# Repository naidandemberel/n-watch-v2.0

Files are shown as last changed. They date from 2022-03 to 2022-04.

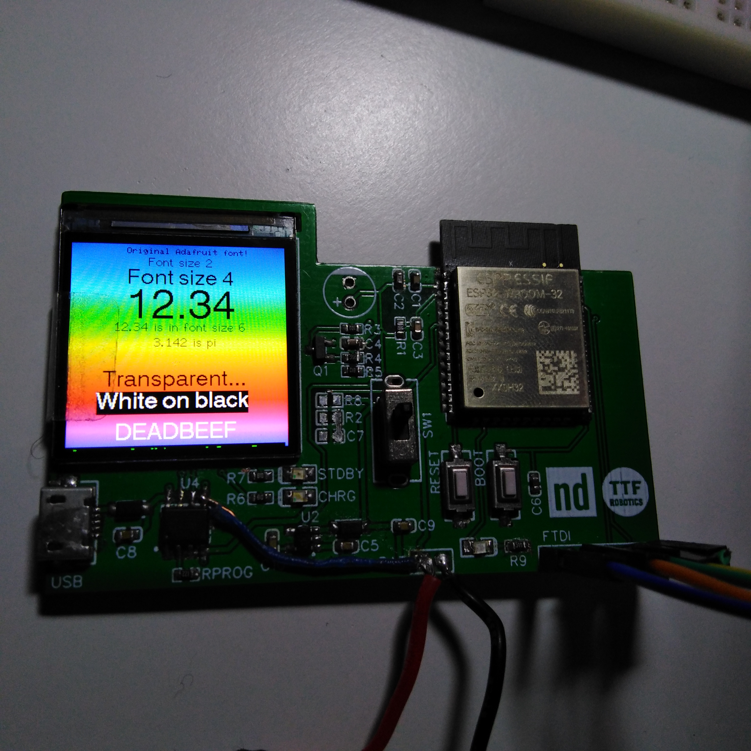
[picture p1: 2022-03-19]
Pictures/IMG_20211001_222228_1.jpg

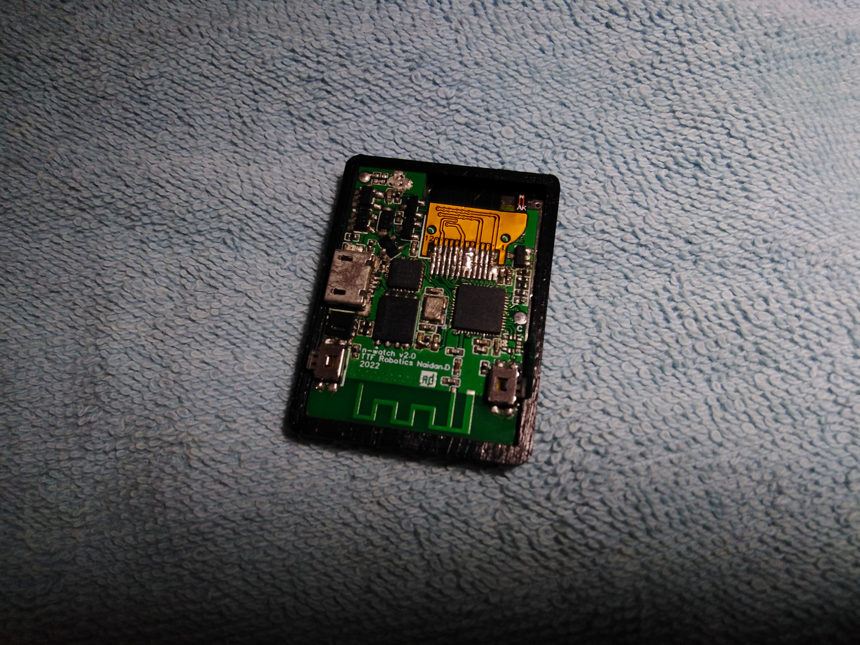
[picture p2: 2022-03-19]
Pictures/IMG_20220121_220617.jpg

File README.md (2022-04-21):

# n-watch-v2.0
n-watch v2.0 is an open source, hackable, smart watch based on ESP32. <br/>
Hackaday: https://hackaday.io/project/184473-n-watch-v20 for more information. <br/>



Hardware <br/>
• Microcontroller: ESP32-D0WDQ6-V3 <br/>
• Display: 240x240 ST7789 IPS <br/>
• Battery: 150mah LiPo <br/>
• Temperature sensor: SHT20 <br/>
• Battery charger IC: TP4054 <br/>
• Flash IC: W25Q32JVZPIQ <br/>
• USB to UART IC: CP2104 <br/>

Features <br/>
• Arduino based <br/>
• WiFi + Bluetooth 4.0 <br/>
• The case consists of 2 parts (bottom and top) <br/>
• 2 programmable buttons <br/>
• Shows time, date, voltage of battery, percent of battery, temperature <br/>
• Any 20mm watchband <br/>
• The battery life is horrible. I tried to minimize all the power consumption (3-4 hours) <br/>
• Has own app <br/>

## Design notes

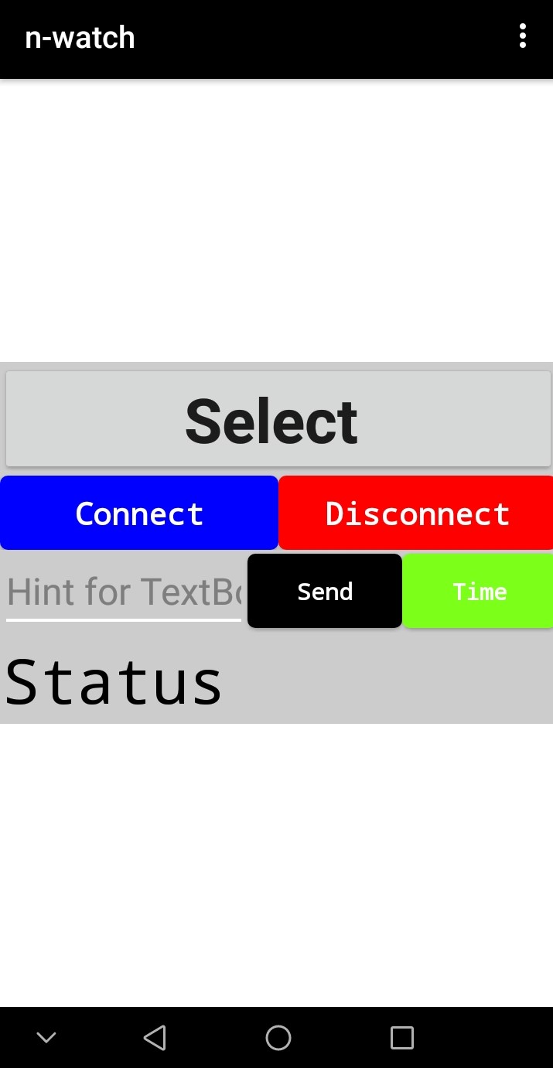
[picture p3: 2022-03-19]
n-watch v2.0 phone app/Pictures/Screenshot_20220319-151742.jpg

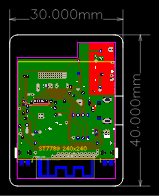
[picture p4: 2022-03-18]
Pictures/PCB_PCB_n-watch v2.0_2022-02-12.png

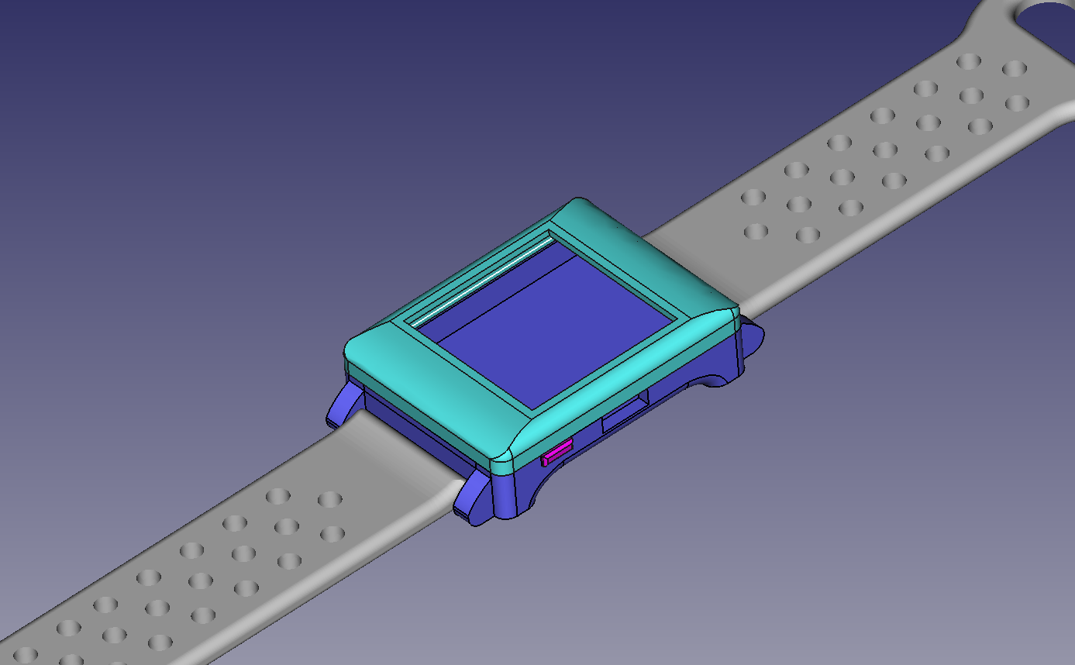
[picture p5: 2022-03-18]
Pictures/Screenshot 2022-02-20 202150.png

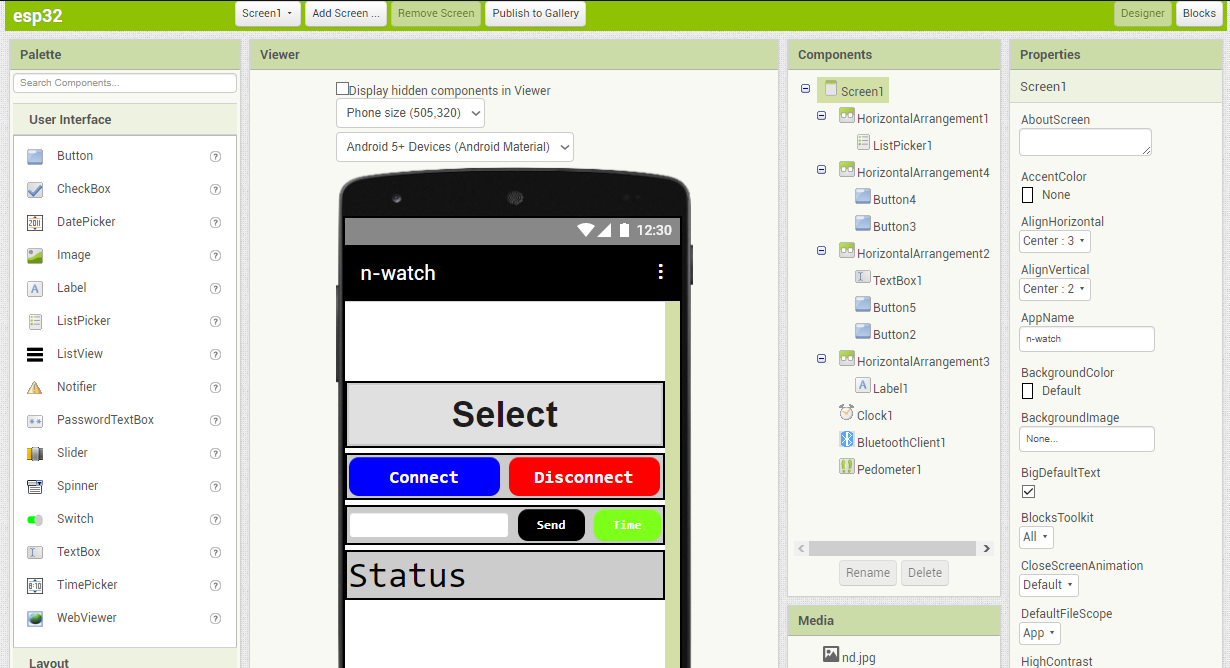
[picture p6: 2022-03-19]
n-watch v2.0 phone app/Pictures/Capture.PNG

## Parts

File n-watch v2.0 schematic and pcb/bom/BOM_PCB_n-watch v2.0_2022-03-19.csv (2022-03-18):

ID | Name | Designator | Footprint | Quantity | Manufacturer Part | Manufacturer | Supplier | Supplier Part | Price
1 | ST7789-240X240 COPY | U8 | ST7789-240X240_NAIDAN | 1
2 | K2-1114SA-A4SW-06 | SW1,SW2 | KEY-SMD_4P-L4.8-W4.6-P1.70-LS6.2 | 2 | K2-1114SA-A4SW-06 | HRO | LCSC | C136662 | 0.156
3 | CP2104-F03-GMR | U5 | QFN-24_L4.0-W4.0-P0.50-BL-EP2.6 | 1 | CP2104-F03-GMR | SILICON LABS | LCSC | C47015 | 2.361
4 | BMA400 | U10 | LGA-12_L2.0-W2.0-P0.50-BL | 1 | BMA400 | Bosch Sensortec | LCSC | C437655 | 5.28
5 | ESP32-D0WDQ6-V3 | U1 | QFN-48_L6.0-W6.0-P0.40-BL-EP4.2 | 1 | ESP32-D0WDQ6-V3 | ESPRESSIF 乐鑫 | LCSC | C967020 | 2.7
6 | MBR0530 | D2 | SOD-123_L2.8-W1.8-LS3.7-RD | 1 | MBR0530 | CJ | LCSC | C77336 | 0.033
7 | CJ2301 S1 | Q4 | SOT-23-3_L3.0-W1.7-P0.95-LS2.9-BR | 1 | CJ2301 S1 | CJ | LCSC | C8547 | 0.042
8 | 10k | R2,R4,R5,R6,R7,R10,R11,R12,R13,R15 | R0402 | 10
9 | 100k | R8,R9 | R0402 | 2
10 | RT9013-33GB | U2 | SOT-23-5 | 1 | RT9013-33GB | RICHTEK | LCSC | C47773 | 0.375
11 | 1uF | C3 | C0402 | 1
12 | 0.1uF | C1,C2,C9,C17 | C0402 | 4
13 | 12pF | C18,C19 | C0402 | 2
14 | 3.3nF/6.3V/(10%) | C20 | C0402 | 1
15 | 10nF/6.3V(10%) | C21 | C0402 | 1
16 | 4.7pF | C22 | C0402 | 1
17 | 2.4pF | C23 | C0402 | 1
18 | 2.4nH | L2 | L0402 | 1
19 | S8050 | Q1,Q2,Q3 | SOT-23-3_L2.9-W1.3-P1.90-LS2.4-BR | 3 | S8050 | JSMSEMI | LCSC | C916390 | 0.008
20 | 10 | R1 | R0402 | 1
21 | 1k | R3,R16 | R0402 | 2
22 | 20k(5%) | R14 | R0402 | 1
23 | 4.7k | R17,R18 | R0402 | 2
24 | W25Q32JVZPIQ | U3 | WSON-8_L6.0-W5.0-P1.27-BL-EP | 1 | W25Q32JVZPIQ | Winbond Elec | LCSC | C571260 | 0.844
25 | TP4054 | U4 | SOT-23-5_L3.0-W1.7-P0.95-LS2.8-BR | 1 | TP4054 | TOPPOWER | LCSC | C32574 | 0.161
26 | SHT20 | U9 | DFN-6_L3.0-W3.0-P0.95-TR-EP | 1 | SHT20 | Sensirion | LCSC | C53865 | 1.964
27 | 40MHz | X1 | OSC-SMD_4P-L3.2-W2.5-BL | 1 | 3225-40M-12PF-10PPM | TKD | LCSC | C337678 | 0.117
28 | PCB ANTENNA 2.4GHZ UNDER MASK | U6 | PCB ANTENNA 2.4GHZ | 1
29 | U254-051T-4BH83-F1B | USB2 | MINI-USB-SMD_U254-051T-4BH83-F1B | 1 | U254-051T-4BH83-F1B | XKB Enterprise | LCSC | C319162 | 0.063
30 | 4.7uF | C8 | C0402 | 1
31 | LED-0603_R | LED1 | LED0603_RED | 1 | 19-217/R6C-AL1M2VY/3T | EVERLIGHT(台湾亿光) | LCSC | C72044 | 0.016

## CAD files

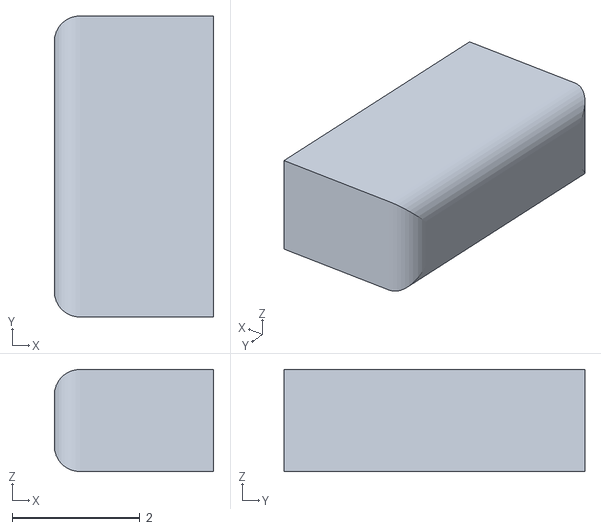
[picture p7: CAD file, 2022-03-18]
n-watch v2.0 case design/n-watch v2.0 case-Button.stl
2.50 x 4.72 x 1.60

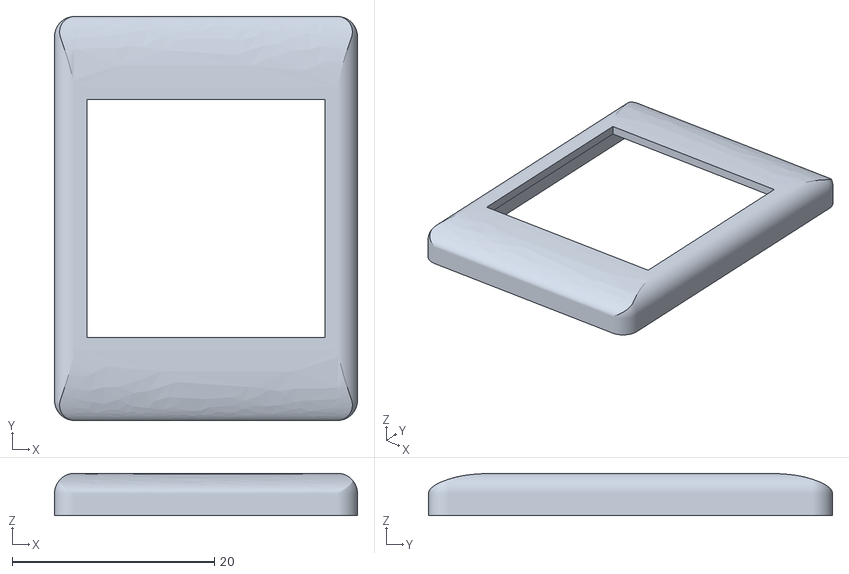
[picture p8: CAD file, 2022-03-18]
n-watch v2.0 case design/n-watch v2.0 case-Top.stl
30.0 x 40.0 x 4.20

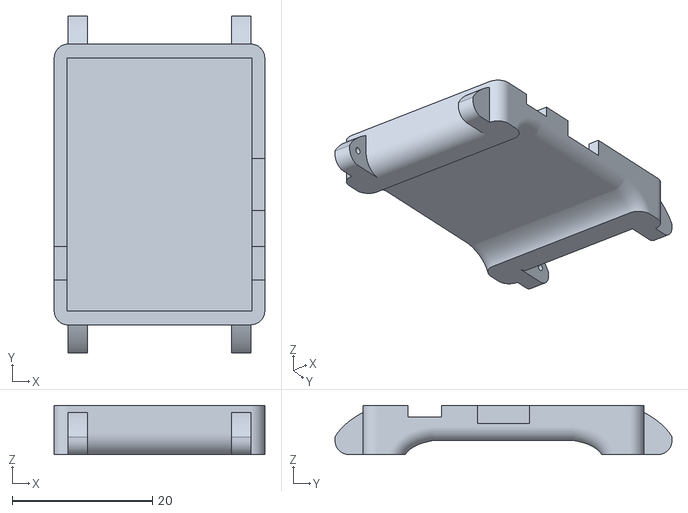
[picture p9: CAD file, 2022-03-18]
n-watch v2.0 case design/n-watch v2.0 case-Bottom.stl
30.0 x 48.0 x 7.00

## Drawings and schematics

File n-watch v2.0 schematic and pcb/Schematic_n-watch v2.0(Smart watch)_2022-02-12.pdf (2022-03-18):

## Power

## Sensors

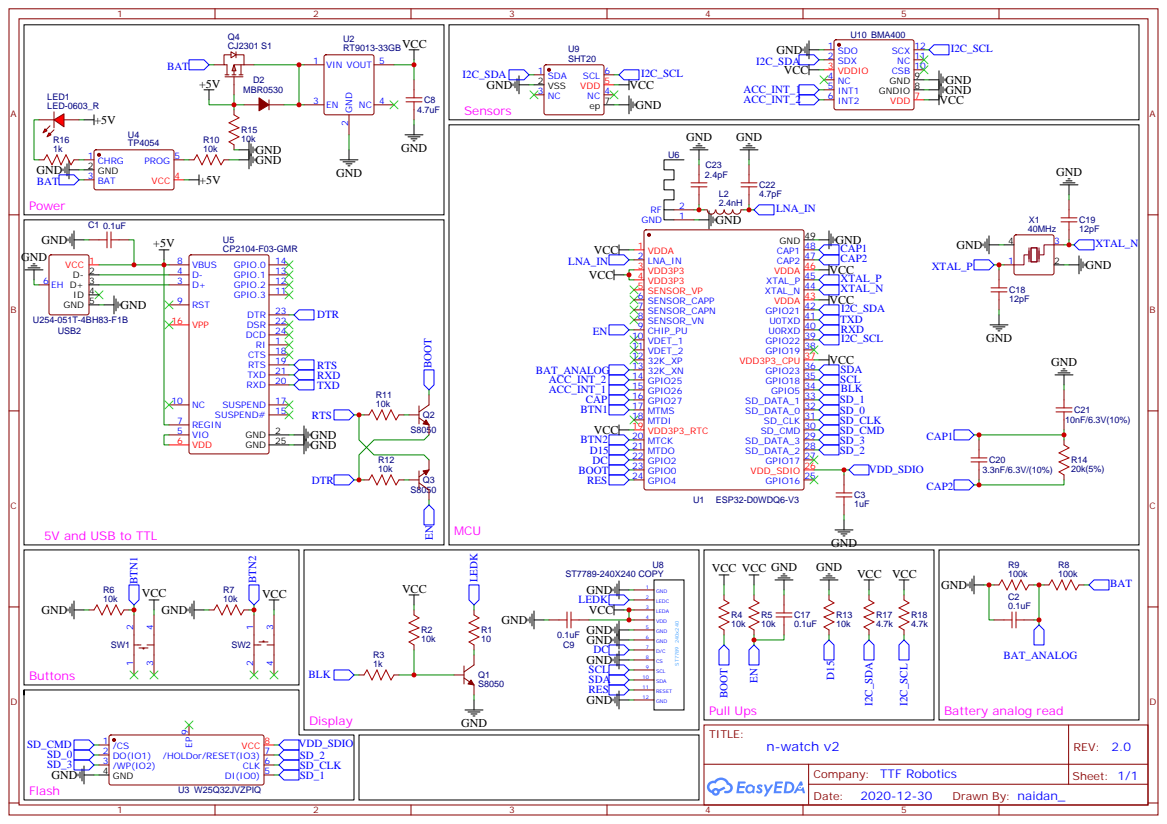
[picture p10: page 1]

5V and USB to TTL

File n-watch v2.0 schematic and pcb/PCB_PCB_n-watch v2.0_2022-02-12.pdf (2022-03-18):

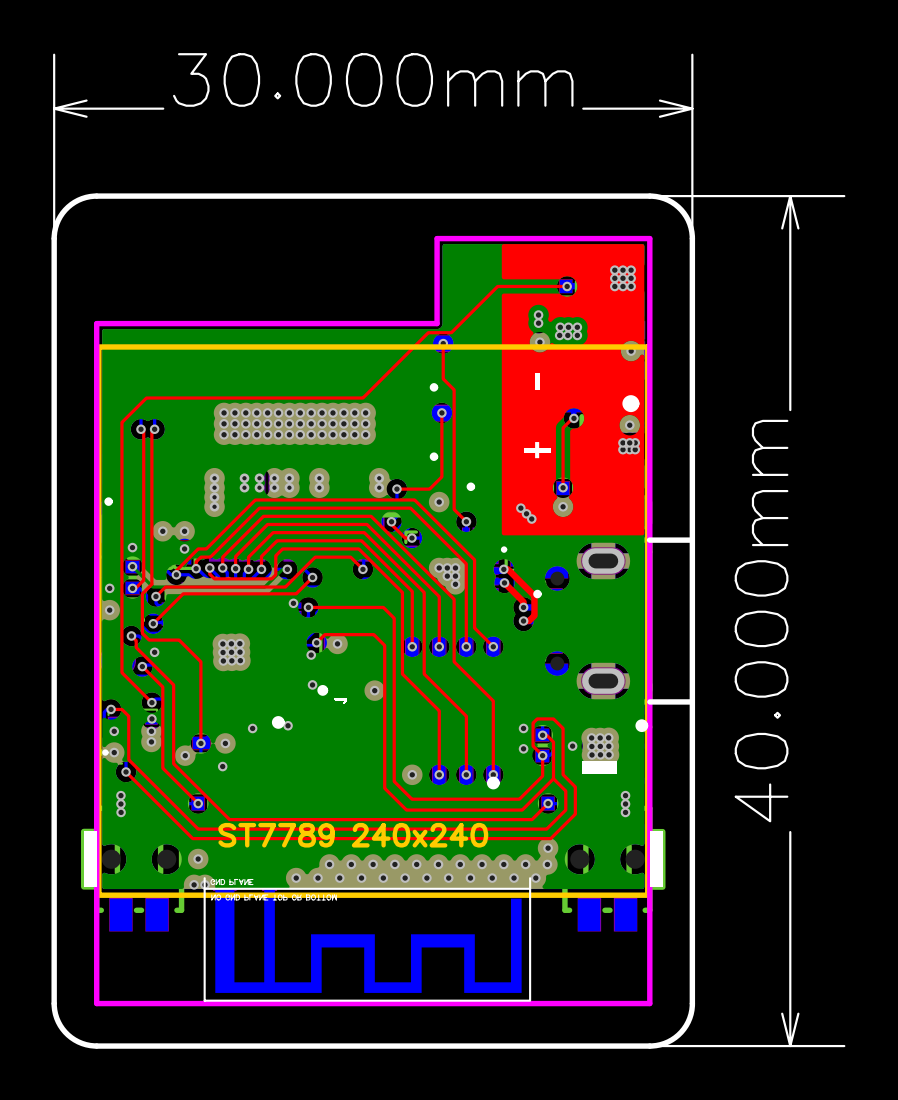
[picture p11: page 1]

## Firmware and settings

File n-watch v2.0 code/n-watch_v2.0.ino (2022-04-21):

#include "Declarations.h"

void setup()
{
  setCpuFrequencyMhz(80); // setting CPU frequency to 80MHz to reduce power consumption
  rtc_clk_slow_freq_set(RTC_SLOW_FREQ_8MD256);// setting rtc slow frequency(more accurate in sleep modes)
  //use arduino-esp32 version 2.0.0 (2.0.2 won't work)

#ifdef DEBUG
  Serial.begin(115200);
  Serial.println("n-watch v2.0");
#endif

  pinMode(leftPin, INPUT);
  pinMode(rightPin, INPUT);
  
  Wire.begin(I2C_SDA, I2C_SCL);
  
  initLCD();
  initBL();
  
  delay(100);
}

void sleep()
{
  digitalWrite(backLight, LOW);

  tft.writecommand(0x10);
  delay(5);// Sleep

  //gpio_deep_sleep_hold_en();
 
  if (timeseted == true)
  {
    esp_wifi_stop();
    btStop();
    esp_bt_controller_disable();
    esp_bluedroid_disable();
  }
  
  //adc_power_off();
  //WiFi.mode(WIFI_OFF);
  
  esp_sleep_enable_ext0_wakeup(GPIO_NUM_14, 1);
  Serial.println("Sleping");
  Serial.flush();
  esp_light_sleep_start();
  //esp_deep_sleep_start();
}

void onWakeup()
{
  //gpio_deep_sleep_hold_dis();
  digitalWrite(backLight, HIGH);
  tft.writecommand(0x11);
  delay(120);
  tft.fillScreen(TFT_BLACK);
}

boolean wakeupCheck()
{
  if(digitalRead(leftPin) == 1)
  {
    return 1;
  }
  else
  {
    return 0;
  }
}

void battery()
{
  batvalue = analogRead(batteryPin)*(6.6/4096);
  percent = (batvalue-3.0)/0.75*100;
}

void loop()
{
  if (wakeupCheck())
  {
    if (timeseted == true)
    {
      mainDisplay();
      if(displayHold == true)
      {
        delay(displayTime);
      }
    }
    else
    {
      if (SerialBT.available() > 0)
      {
        setRTC();
      }
      displayBLconnect();
    }
  }
  else
  {
    sleep();

    onWakeup();
  }
}

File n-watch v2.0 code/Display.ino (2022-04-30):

void initLCD()
{
  pinMode(backLight, OUTPUT);
  digitalWrite(backLight, HIGH);
  tft.init();
  tft.setRotation(2);
  tft.fillScreen(TFT_BLACK);
}

void displayBLconnect()
{
  tft.setSwapBytes(true);
  tft.pushImage(50, 20, 140, 140, BL);
  tft.setTextColor(TFT_WHITE, TFT_BLACK);
  tft.setTextSize(2);
  tft.setCursor(10, 175);
  tft.print("Please connect with");
  tft.setCursor(0, 200);
  tft.print("your phone");
}

void mainDisplay()
{
  unsigned long currentTime = millis();
  if (currentTime - previous >= interval)
  {
    temp = sht.readTemperature();
    humi = sht.readHumidity();
    previous = currentTime;
    battery();
  }
  mi = rtc.getMinute();
  ho = rtc.getHour(true);
  if (mi < 10) {
    mistring = "0" + String(mi);
  }
  else {
    mistring = String(mi);
  }
  if (ho < 10) {
    hostring = "0" + String(ho);
  }
  else {
    hostring = String(ho);
  }
  tft.setTextColor(TFT_WHITE, TFT_BLACK);
  tft.setTextFont(7);
  tft.setTextSize(1);
  tft.setCursor(45, 80);
  tft.print(hostring + ":" + mistring);

  tft.setTextFont(1);
  tft.setTextSize(2);
  tft.setCursor(30, 180);
  tft.print(rtc.getDate());

  tft.setCursor(10, 10);
  tft.print(temp, 1);
  tft.setCursor(60, 10);
  tft.print("C");

  tft.setCursor(10, 30);
  tft.print(humi, 1);
  tft.setCursor(60, 30);
  tft.print("%");
  
  tft.setCursor(175, 10);
  tft.print(String(percent,0)+"%");
  tft.setCursor(175, 30);
  tft.print(String(batvalue,2)+"V");
}

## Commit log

2022-03-19 Altium Designer Update
    [PCB_n-watch v2.0_2022-03-19.pcbdoc, n-watch v2.0_2022-03-19.schdoc]
2022-04-13 Update n-watch_v2.0.ino
    Added battery analogRead() function
2022-04-13 Update Display.ino
    Added functions to print battery percentage
2022-04-21 Update n-watch_v2.0.ino
    Updated code battery measuring code
